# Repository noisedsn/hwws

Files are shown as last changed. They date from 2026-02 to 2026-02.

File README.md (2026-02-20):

# HWWS

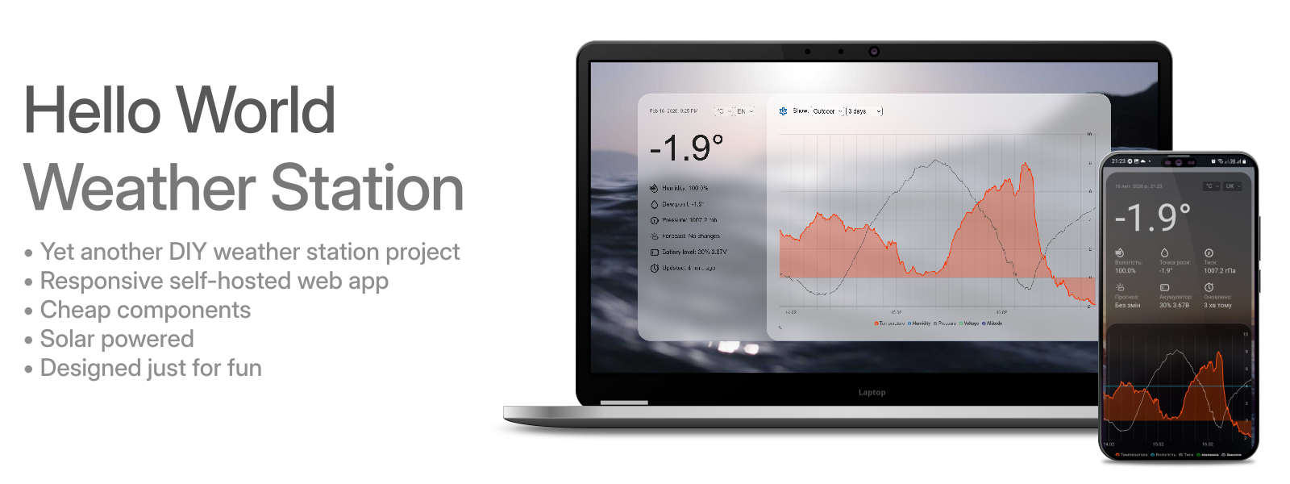
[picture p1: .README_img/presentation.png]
HWWS


A humble weather station project created few years ago just because I wanted to play in some different fields, from hardware design and programming in few different languages to UI-UX and graphics design.

## Web server

Simple PHP backend that allows managing users, adding multiple sensors, making them public or private (available only for logged in users). Serverless SQLite database was chosen for simplicity. To prevent flooding, sensors are authorized with a simple Digest-like authentication and must be paired using the PIN code issued by the server.

Front-end features a responsive design and multilangual support.

### Requirements: 
- PHP 8+
- php-sqlite3

### Installation:
- Copy all files from the "webserver" directory to your server.
- Make sure that directories "/assets/favicon/cache" and "/db" are writable.
- Navigate to the selected URL and complete the setup process.

During the installation, the first created user will receive Administrator rights and will be able to add new users and sensors. Non-admin users can only view the configuration and access private sensors.

Next, add a sensor. Station elevation (in meters) is required to recalculate local atmospheric pressure to standard sea-level pressure.

## Hardware

### For a bare minimum:

- Microcontroller - ESP8266 or ESP32-C3.
- Temperature, humidity and pressure sensor - BME280.

### Optional (battery, solar charging, battery monitoring, improved stability): 

- TP4056 + DW01A charging module
- 6V Solar panel
- Single cell Li-ion or Lipo battery
- Few other discrete components, to complete power circuits. D1 and D1 must be a Zener diodes with a low forward voltage drop.

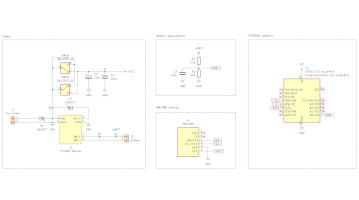
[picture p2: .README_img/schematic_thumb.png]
Schematic

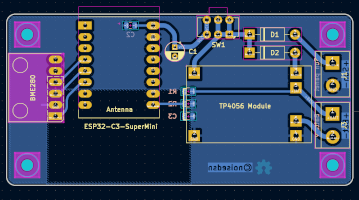
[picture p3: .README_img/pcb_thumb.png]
PCB

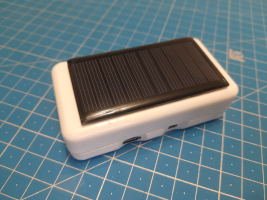
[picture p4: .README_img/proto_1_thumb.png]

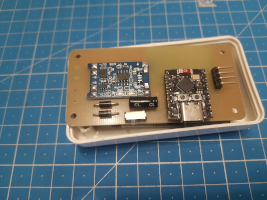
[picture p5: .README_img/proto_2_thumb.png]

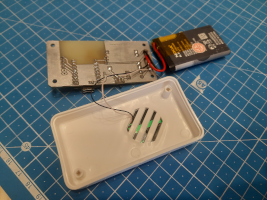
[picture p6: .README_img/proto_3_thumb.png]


PCB designs are single-sided, made in KiCad and optimized for DIY etching at home (but can be manufactured as well). The photo shows my prototyping board, etched from a laser-printed page using citric acid + hydrogen peroxide recipe.

## Firmware

Sensor firmware is fully configurable via built-in web interface. Developed using Arduino IDE.

### Pairing process:
After first flashing, the microcontroller's WiFi access point will be active immediately, allowing you to pair the sensor with the web server. Connect, using the following credentials:

- AP SSID: `Weather Sensor`
- Password: `123456789`
- Open in browser: `192.168.4.1`

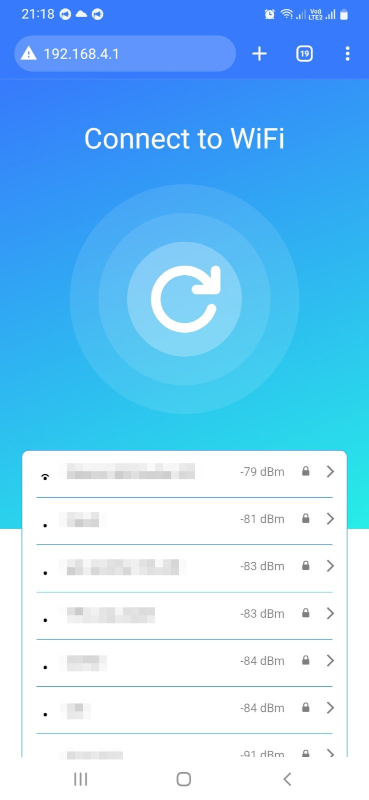
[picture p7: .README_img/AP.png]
HWWS AP


Next, finish the sensor setup:
- Enter SSID and password of your WiFi network.
- Server URL (homepage) where the HWWS webserver was installed.
- PIN code issued by the server. It is used to authenticate and identify sensors. 

If you need to change the settings later, press the reset button twice within a second and it will enter pairing mode again.

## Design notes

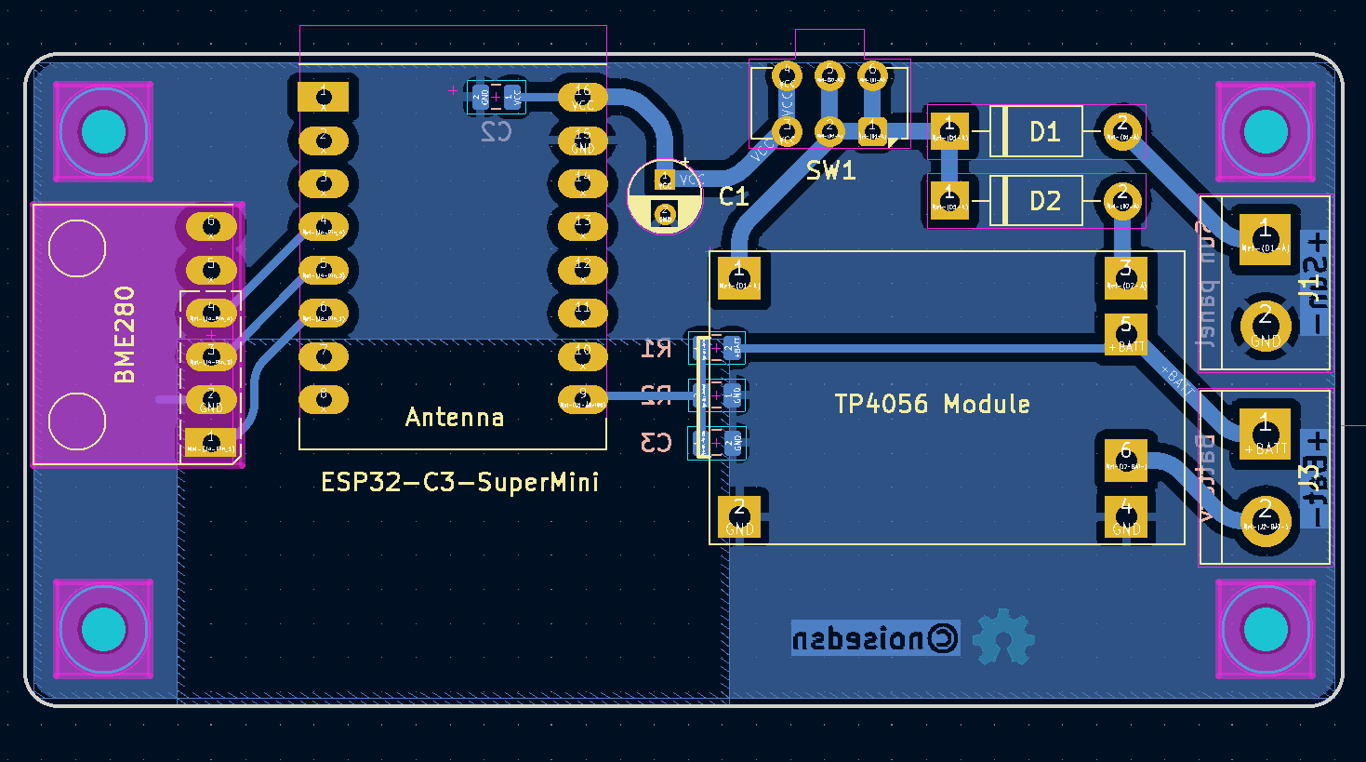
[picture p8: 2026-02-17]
.README_img/pcb.png

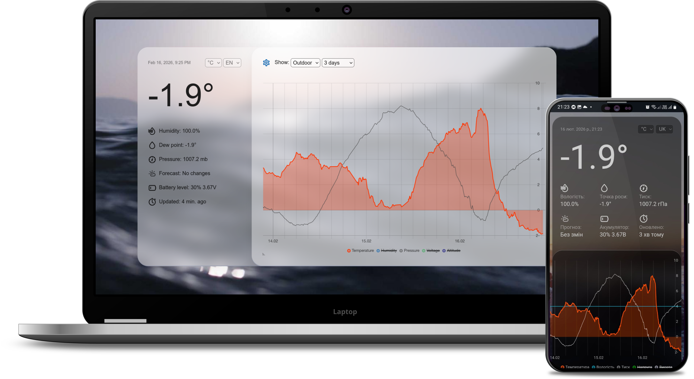
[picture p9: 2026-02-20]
.README_img/screenshots.png

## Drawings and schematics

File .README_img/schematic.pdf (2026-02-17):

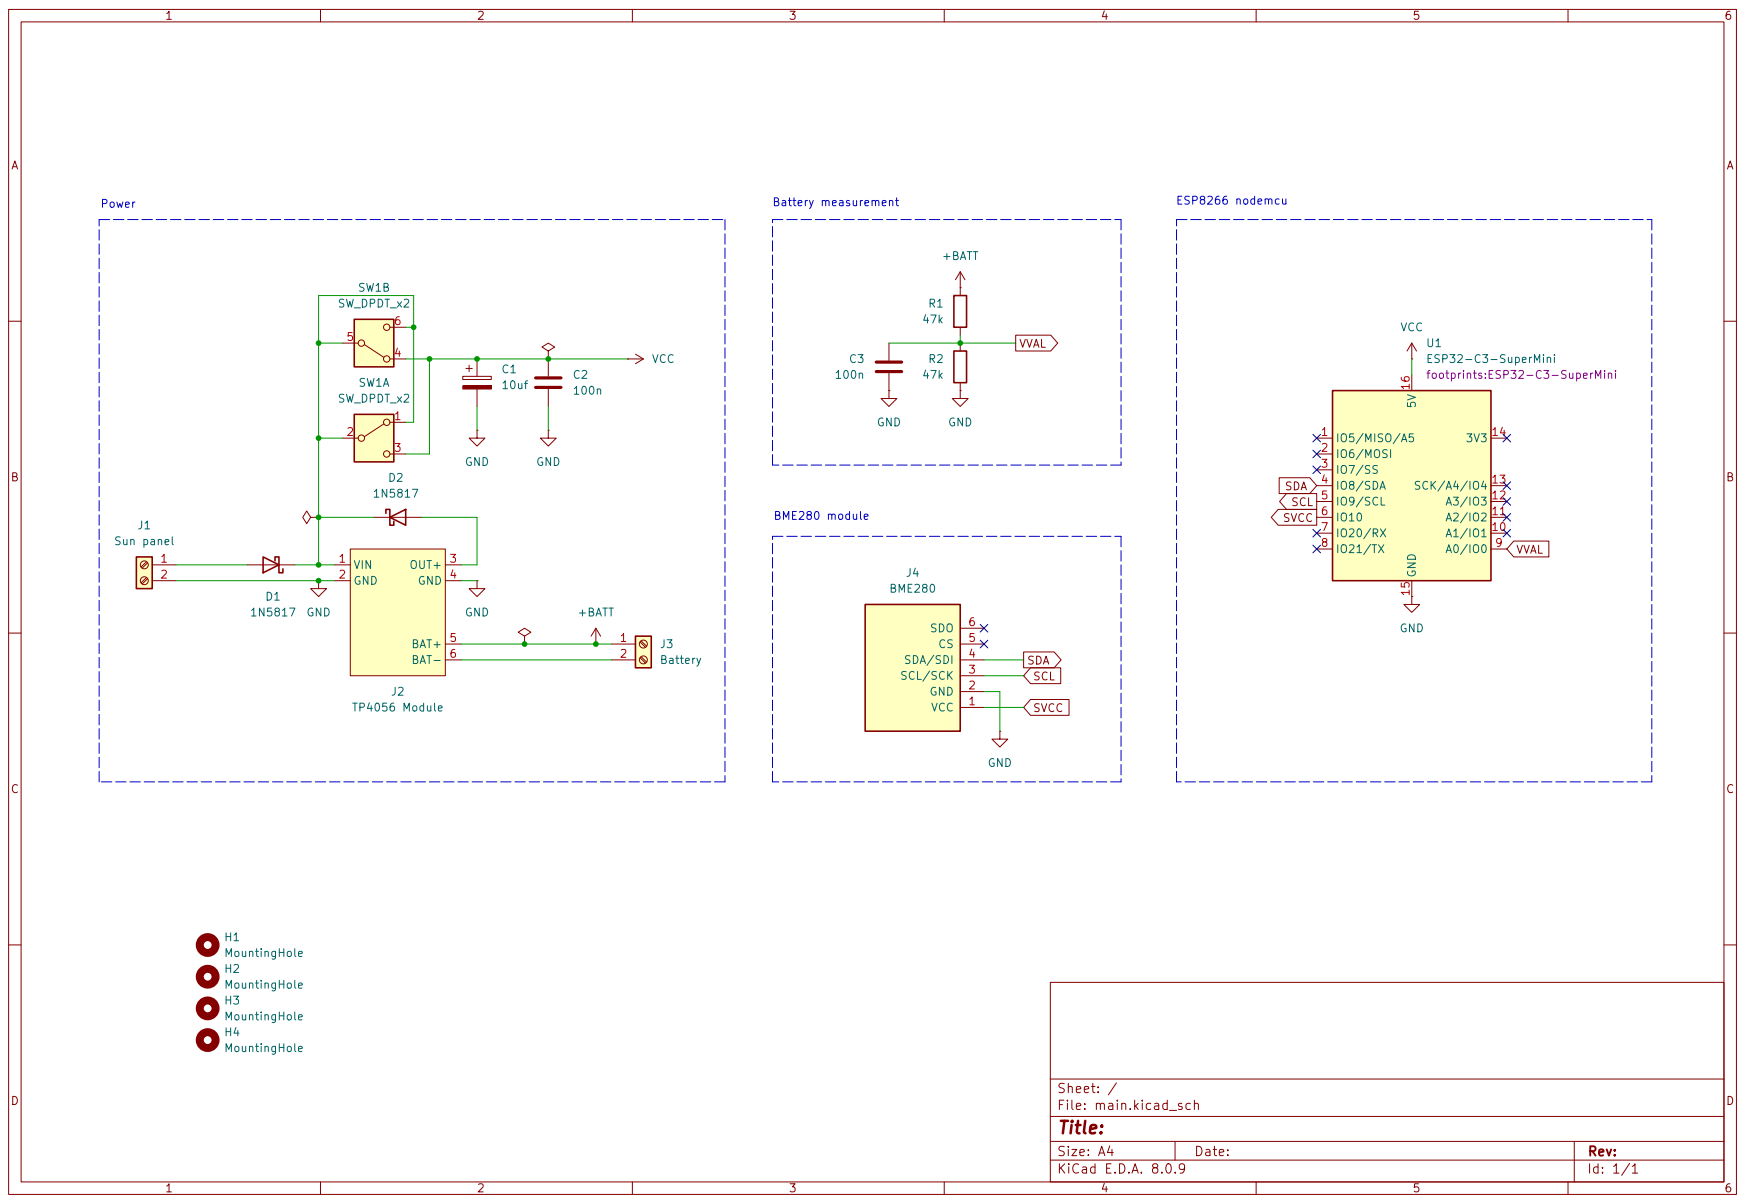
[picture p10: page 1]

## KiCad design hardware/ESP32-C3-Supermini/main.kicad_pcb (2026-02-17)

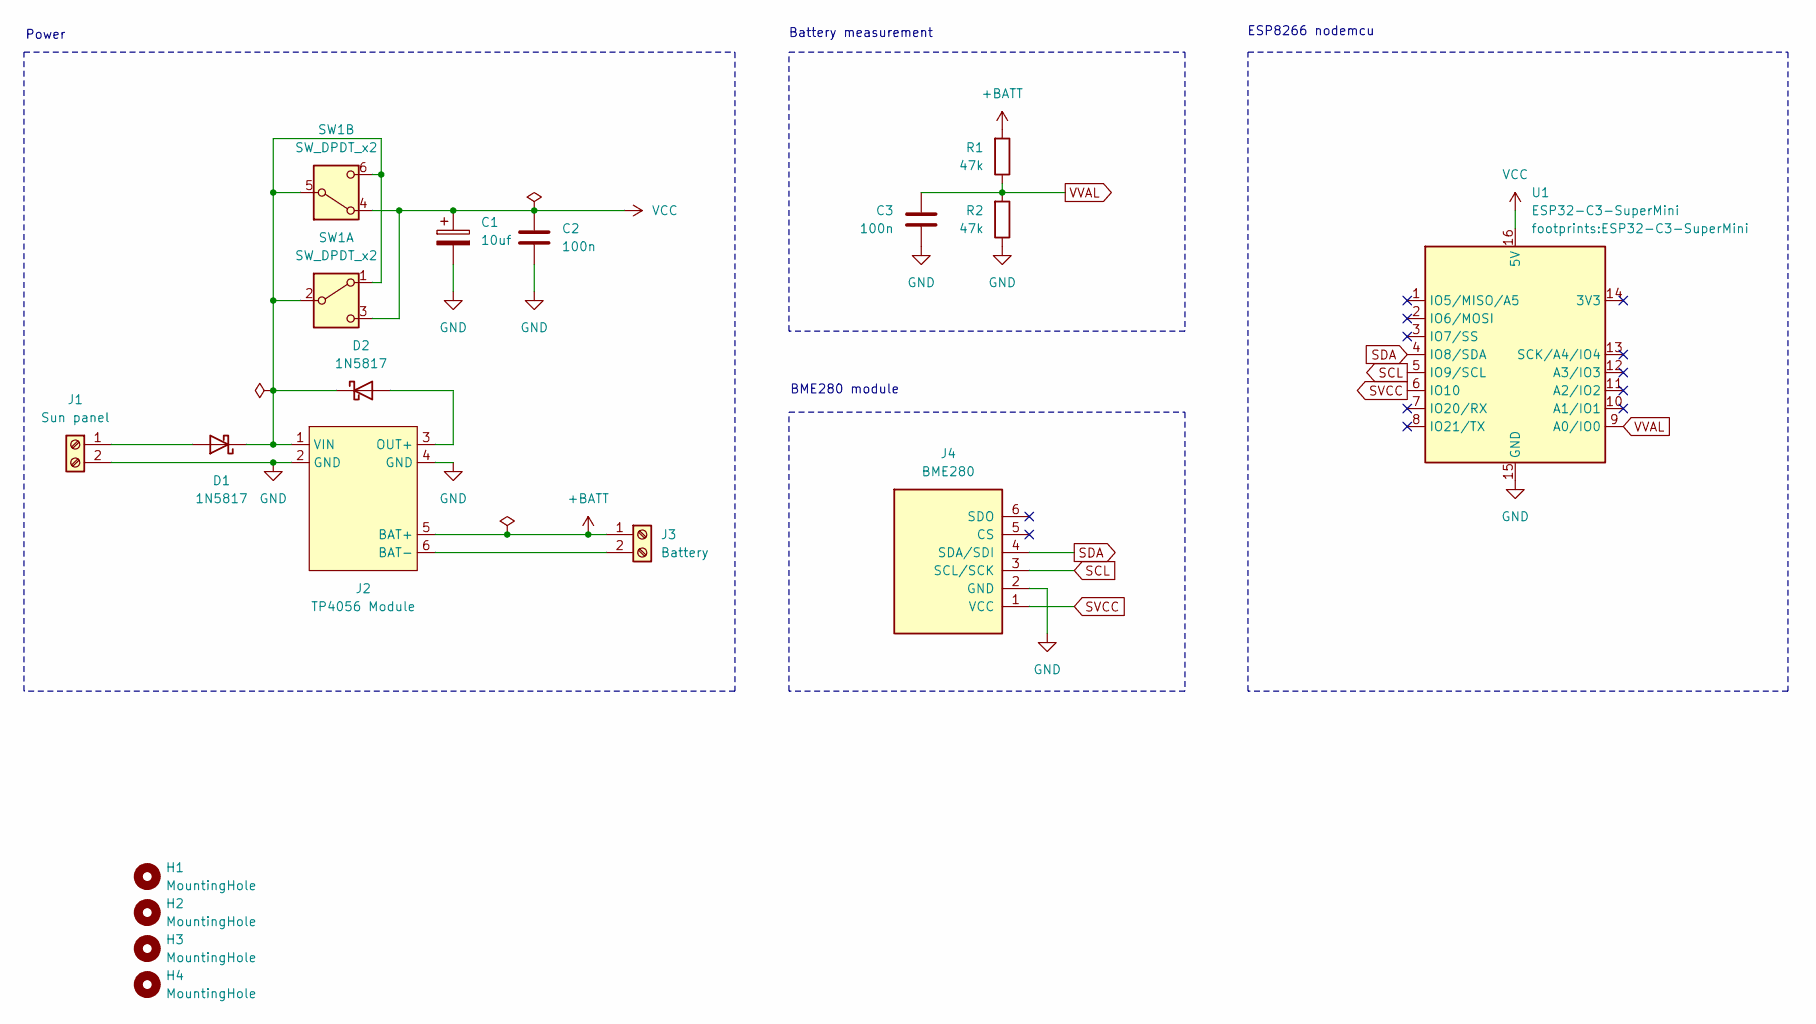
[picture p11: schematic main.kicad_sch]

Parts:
C1: 10uf; CP_Radial_D4.0mm_P2.00mm
C2, C3: 100n; C_0805_2012Metric
D1, D2: 1N5817; D_DO-41_SOD81_P10.16mm_Horizontal
H1, H2, H3, H4: MountingHole; MountingHole_2.5mm
J1: Sun panel; TerminalBlock_bornier-2_P5.08mm
J2: TP4056 Module; Charge_Controller_TP4056
J3: Battery; TerminalBlock_bornier-2_P5.08mm
J4: BME280; BME280 module
R1, R2: 47k; R_0805_2012Metric
SW1: SW_DPDT_x2
U1: ESP32-C3-SuperMini

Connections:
+BATT: J2.5 (BAT+), J3.1, R1.2
GND: C1.2, C2.2, C3.2, J1.2, J2.2 (GND), J2.4 (GND), J4.2 (GND), R2.1, U1.15 (GND)
unnamed: D1.2 (A), J1.1
unnamed: D1.1 (K), D2.1 (K), J2.1 (VIN), SW1.1 (A), SW1.2 (B), SW1.5 (B), SW1.6 (C)
unnamed: D2.2 (A), J2.3 (OUT+)
unnamed: J2.6 (BAT-), J3.2
SCL: J4.3 (SCL/SCK), U1.5 (IO9/SCL)
SDA: J4.4 (SDA/SDI), U1.4 (IO8/SDA)
SVCC: J4.1 (VCC), U1.6 (IO10)
VCC: C1.1, C2.1, SW1.3 (C), SW1.4 (A), U1.16 (5V)
VVAL: C3.1, R1.1, R2.2, U1.9 (A0/IO0)

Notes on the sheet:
ESP8266 nodemcu
BME280 module
Battery measurement
Power

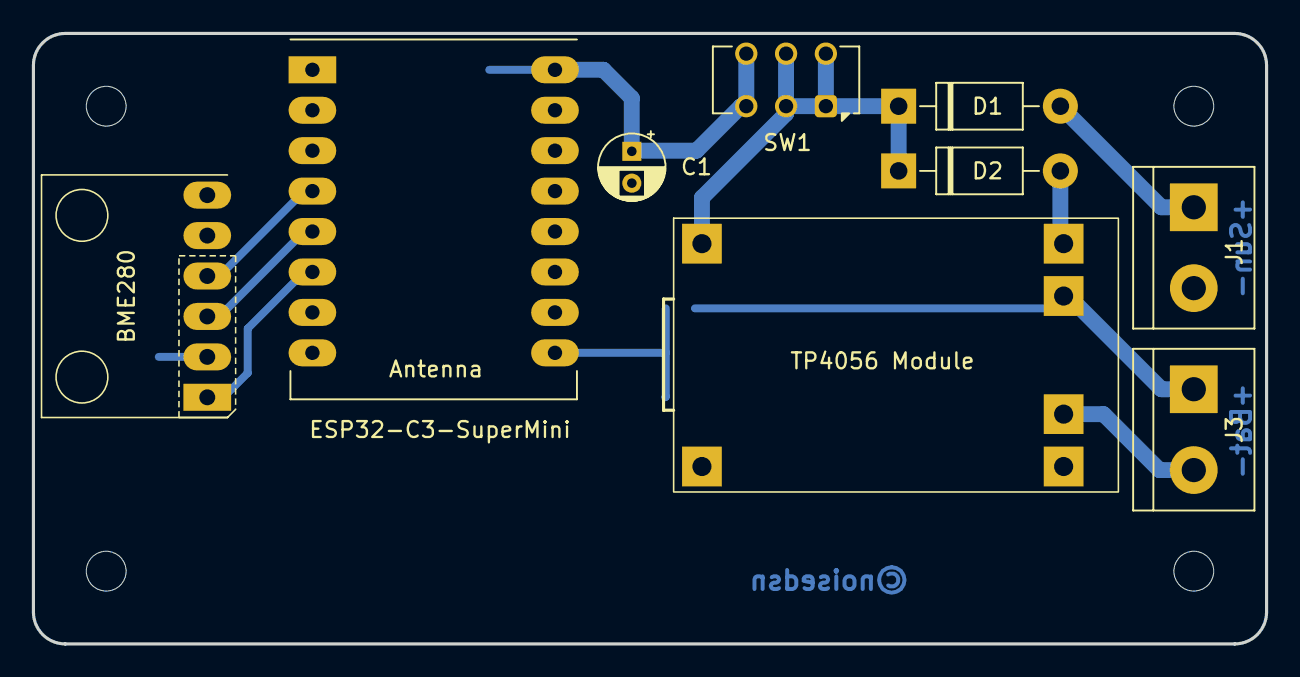
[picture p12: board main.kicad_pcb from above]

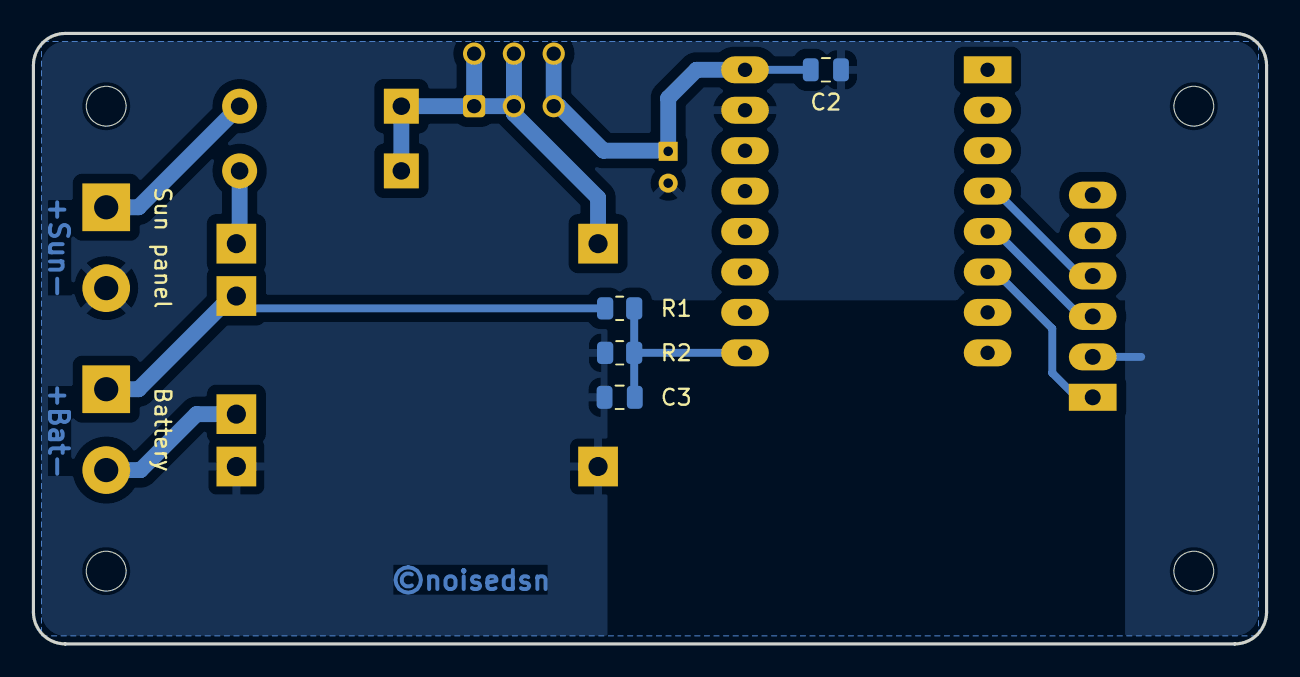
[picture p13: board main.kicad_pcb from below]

Board: 2 copper layers, 77.5 x 38.4 mm, 17 parts (4 on the bottom side), 11 nets.

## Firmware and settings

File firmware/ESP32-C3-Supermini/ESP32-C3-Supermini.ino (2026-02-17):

/*
  Sketch Title: HWWS firmware (ESP8266 version)
  Description: Hello World Weather Sensor.
  Author: noisedsn
  Version: 0.9
*/

#include <WiFi.h>
#include <Adafruit_BME280.h>
#include <HTTPClient.h>
#include <WebServer.h>
#include <WiFiClientSecure.h>  // Required for HTTPS
#include <Preferences.h>
#include <MD5Builder.h>
#include "html_template.h"  // Access Point html templates

#define LED 8   // LED pin
#define PWR 10  // Pin that will power the sensor (for battery-saving)
#define BAT A0  // Analog channel to measure battery voltage
#define SEALEVELPRESSURE_HPA (1013.25)
#define RESET_FLAG 0xA5
#define DOUBLE_RESET_DELAY_MS 1000
#define RW_MODE false
#define RO_MODE true

const String ap_ssid = "Weather Sensor";  // Initial access point network credentials
const String ap_pass = "123456789";
const float dividerRatio = 0.5;           // Resistor divider ratio ractor. Tweak it slightly to get correct battery voltage.

// Other global variables
String serverHost;
String serverPath;
String pinCode;
int sleepTime;
String sessionCookie = "";

// Preferences object
Preferences prefs;


// Function declarations
bool putValue(int address, int length, String value);
void handleWebServer();
bool testWiFi();
String scanWiFi();
void deepSleep();


// Setup function
void setup() {

  pinMode(LED, OUTPUT);  // Initialize the LED pin as an output
  pinMode(PWR, OUTPUT);  // Initialize the PWR pin as an output
  pinMode(BAT, INPUT);   // Initialize the BAT pin as an input

  digitalWrite(PWR, HIGH);
  digitalWrite(LED, LOW);  // Low = thrned on

  analogReadResolution(12);
  analogSetAttenuation(ADC_11db);

  Serial.begin(115200);

  delay(10);
  Serial.println();
  Serial.println("Starting");
  Serial.println();

  // Read preferences
  uint8_t resetFlag;

  prefs.begin("sensor", RW_MODE);

  if (!prefs.isKey("wifiSsid")) {
    // First boot, configuring required
    resetFlag = RESET_FLAG;
  } else {
    String wifiSsid = prefs.getString("wifiSsid");
    // Serial.println("wifiSsid: " + wifiSsid);

    String wifiPass = prefs.getString("wifiPass");
    // Serial.println("wifiPass: " + wifiPass);

    serverHost = prefs.getString("serverHost");
    // Serial.println("serverHost: " + serverHost);

    serverPath = prefs.getString("serverPath");
    // Serial.println("serverPath: " + serverPath);

    pinCode = prefs.getString("pinCode");
    // Serial.println("pinCode: " + pinCode);

    sleepTime = prefs.getInt("sleepTime");
    // Serial.println("sleepTime: " + sleepTime);

    resetFlag = prefs.getUChar("resetFlag");
    // Serial.println("resetFlag: " + (String)resetFlag);
  
    WiFi.begin(wifiSsid.c_str(), wifiPass.c_str());
  }

  // Double-click on reset magic starts here
  // Ignore deep sleep wakeups
  if (esp_sleep_get_wakeup_cause() != ESP_SLEEP_WAKEUP_UNDEFINED) {
    return;
  }

  if (resetFlag == RESET_FLAG) {
    // Second reset → double click
    // Serial.println("Clearing resetFlag");
    prefs.putUChar("resetFlag", 0);

    Serial.println("Turning the Access Point On");
    WiFi.mode(WIFI_STA);
    WiFi.softAP(ap_ssid, ap_pass);

    Serial.println();
    Serial.println("--------------------------------------------");
    Serial.println("To configure the sensor, connect to the next");
    Serial.println("Access Point and open IP address in browser:");
    Serial.println("--------------------------------------------");
    Serial.println("SSID: " + (String)ap_ssid);
    Serial.println("Pass: " + (String)ap_pass);
    Serial.println("IP:   " + WiFi.softAPIP().toString());
    Serial.println();

    handleWebServer();

    return;
  }

  // First reset
  // Serial.println("Raising resetFlag");
  prefs.putUChar("resetFlag", RESET_FLAG);

  // Give time for second reset
  delay(DOUBLE_RESET_DELAY_MS);

  // No second reset → clear flag
  // Serial.println("Clearing resetFlag");
  prefs.putUChar("resetFlag", 0);
  prefs.end();
}


// Main function
void loop() {

  digitalWrite(LED, HIGH);

  // Taking measurements
  float temperature;
  float pressure;
  float altitude;
  float humidity;
  float millivolts = 0.0;
  float voltage = 0.0;

  Adafruit_BME280 bme;  // I2C

  if (bme.begin(0x76)) {
    temperature = bme.readTemperature();
    Serial.println("temperature: " + (String)temperature);

    pressure = (bme.readPressure() / 100.0F);
    Serial.println("pressure: " + (String)pressure);

    altitude = bme.readAltitude(SEALEVELPRESSURE_HPA);
    Serial.println("altitude: " + (String)altitude);

    humidity = bme.readHumidity();
    Serial.println("humidity: " + (String)humidity);
  } else {
    Serial.println("Sensor unavailable");
    deepSleep();
  }

  for (unsigned int i = 0; i < 5; i++) {
    millivolts += analogReadMilliVolts(BAT);  // Read analog Voltage
    delay(5);                                // Wait for ADC to stabilize
  }
  voltage = millivolts / (dividerRatio * 5000);  // battery voltage by multiplying by resistor divider ratio
  Serial.println("voltage: " + (String)voltage);

  pinMode(LED, OUTPUT);
  digitalWrite(LED, LOW);

  // Sending data to server
  if (testWiFi()) {

    // Use WiFiClient class to create TCP connections
    WiFiClientSecure client;
    const int httpPort = 443;  // 80 is for HTTP / 443 is for HTTPS!

    client.setInsecure();

    if (client.connect(serverHost.c_str(), httpPort)) {

      // First connect without data to get authorization headers
      String url = "https://" + serverHost + serverPath;
      String httpRequestData;

      // Starting HTTPClient
      HTTPClient http;
      http.begin(client, url);

      const char * headerkeys[] = {"Set-Cookie", "Cookie", "X-Custom-Auth"};
      size_t headerkeyssize = sizeof(headerkeys) / sizeof(char*);
      http.collectHeaders(headerkeys, headerkeyssize);

      // Send HTTP GET request
      int httpResponseCode = http.GET();

      // Authorization
      if (http.hasHeader("X-Custom-Auth")) {
        String nonce = http.header("X-Custom-Auth");
        // Serial.println("nonce: " + nonce);

        // Sign the request with pinCode
        MD5Builder md;

        md.begin();
        md.add(pinCode+nonce+temperature+pressure+altitude+humidity+voltage);
        md.calculate();

        String signature = md.toString();

        httpRequestData = (String)"t=" + temperature + "&p=" + pressure + "&a=" + altitude + "&h=" + humidity + "&v=" + voltage + "&s=" + signature;
        Serial.println(url);
      }


      // Set cookie
      if (http.hasHeader("Set-Cookie")) {
        sessionCookie = http.header("Set-Cookie");
        // Serial.printf("New session cookie saved: %s\n", sessionCookie.c_str());
      }

      // Add cookie to the request headers
      if (sessionCookie.length() > 0) {
        http.addHeader("Cookie", sessionCookie);
        http.addHeader("Content-Type", "application/x-www-form-urlencoded");
        // Serial.printf("Session cookie sent: %s\n", sessionCookie.c_str());
      }

      httpResponseCode = http.POST(httpRequestData);

      if (httpResponseCode > 0) {
        Serial.print("HTTP Response code: ");
        Serial.println(httpResponseCode);
        String payload = http.getString();
        Serial.println(payload);
      } else {
        Serial.print("Error code: ");
        Serial.println(httpResponseCode);
      }
      // Free resources
      http.end();

    } else {
      Serial.println("Connection failed: " + serverHost);
      deepSleep();
    }

  } else {
    Serial.println("WiFi unavailable");
    deepSleep();
  }

  digitalWrite(LED, HIGH);
  digitalWrite(PWR, LOW);
  deepSleep();
}


// Helper function for saving user entered settings
bool putValue(const char *target, String value) {
    if (value.length() > 0) {
        prefs.putString(target, value);
        return true;
    }
    return false;
};


// Local webserver at port 80
void handleWebServer() {

  WebServer server(80);
  server.begin();
  String content;

  {
    server.on("/", [&]() {
      String htmlStations = scanWiFi();
      String ipStr = "<small>WiFi SSID of this device is: <strong>" + ap_ssid + "</strong><br> \
        Password: <strong>" + ap_pass + "</strong><br> \
        IP address: <strong>" + WiFi.softAPIP().toString() + "</strong></small>";

      content = html_header + html_index;
      content.replace("{{ htmlStations }}", htmlStations);
      content.replace("{{ htmlContent }}", ipStr);
      server.send(200, "text/html", content);
    });

    server.on("/setting", [&]() {

      prefs.begin("sensor", RW_MODE);
      bool changed = false;

      changed |= putValue("wifiSsid", server.arg("ssid"));
      changed |= putValue("wifiPass", server.arg("pass"));
      changed |= putValue("serverHost", server.arg("host"));
      changed |= putValue("serverPath", server.arg("path"));
      changed |= putValue("pinCode", server.arg("pin"));

      if (server.arg("sleep").length() > 0) {
          prefs.putInt("sleepTime", server.arg("sleep").toInt());
          changed = true;
      }

      prefs.end();

      int statusCode;
      if (changed) {
        statusCode = 200;
        content = html_header + html_blank;
        content.replace("{{ htmlContent }}", "<h1>Success!</h1><p>Settings have been saved. Restarting the sensor.</p>");
        server.send(statusCode, "text/html", content);
        delay(1000);
        ESP.restart();
      } else {
        statusCode = 200;
        content = html_header + html_blank;
        content.replace("{{ htmlContent }}", "<h1>Error</h1><p>No settings changed.</p>");
        server.send(statusCode, "text/html", content);
      }
    });

    server.onNotFound([&]() {
      content = html_header + html_blank;
      content.replace("{{ htmlContent }}", "<h1>Error 404</h1><p>Not found.</p>");
      server.send(404, "text/html", content);
    });
  }

  // Blink LED while webserver is active
  while (true) {
    digitalWrite(LED, HIGH);
    delay(100);
    digitalWrite(LED, LOW);
    delay(100);
    server.handleClient();
  }
}


// Testing if WiFi available
bool testWiFi() {
  int i = 0;
  Serial.print("Testing WiFi...");
  while (i < 20) {
    if (WiFi.status() == WL_CONNECTED) {
      Serial.println(" connected!");
      return true;
    }
    delay(500);
    Serial.print(".");
    i++;
  }
  Serial.println(" not connected.");
  return false;
}

// Scan for available networks
String scanWiFi() {
  Serial.println("Scanning WiFi...");
  int n = WiFi.scanNetworks();

  Serial.println("#  SSID                       RSSI     SEC");
  Serial.println("------------------------------------------");

  String htmlStations;
  for (int i = 0; i < n; ++i) {
    String ssid = WiFi.SSID(i);
    int rssi = WiFi.RSSI(i);
    bool secured = WiFi.encryptionType(i) != WIFI_AUTH_OPEN;
    // Serial
    Serial.printf("%-2d ", i + 1);
    Serial.printf("%-24.24s ", ssid.c_str());
    Serial.printf("%4d dBm   ", rssi);
    Serial.println(secured ? "🔒" : " ");
    // html
    String rssiClass = "";
    if (rssi < -60)
      rssiClass = "medium";
    if (rssi < -70)
      rssiClass = "weak";
    if (rssi < -80)
      rssiClass = "poor";
    String securedClass = (secured ? "secured" : "");
    htmlStations += "<li class=\"" + rssiClass + "\"><span>" + WiFi.SSID(i) + "</span> <small>" + WiFi.RSSI(i) + " dBm <span class=\"" + securedClass + "\"></span></small></li>";
  }

  return htmlStations;
}


void deepSleep() {
  // Serial.println("sleep "+sleepTime);
  ESP.deepSleep((int)sleepTime * 1e6);  //Xe6 - X seconds
}

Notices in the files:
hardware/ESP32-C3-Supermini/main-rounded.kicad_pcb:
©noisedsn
